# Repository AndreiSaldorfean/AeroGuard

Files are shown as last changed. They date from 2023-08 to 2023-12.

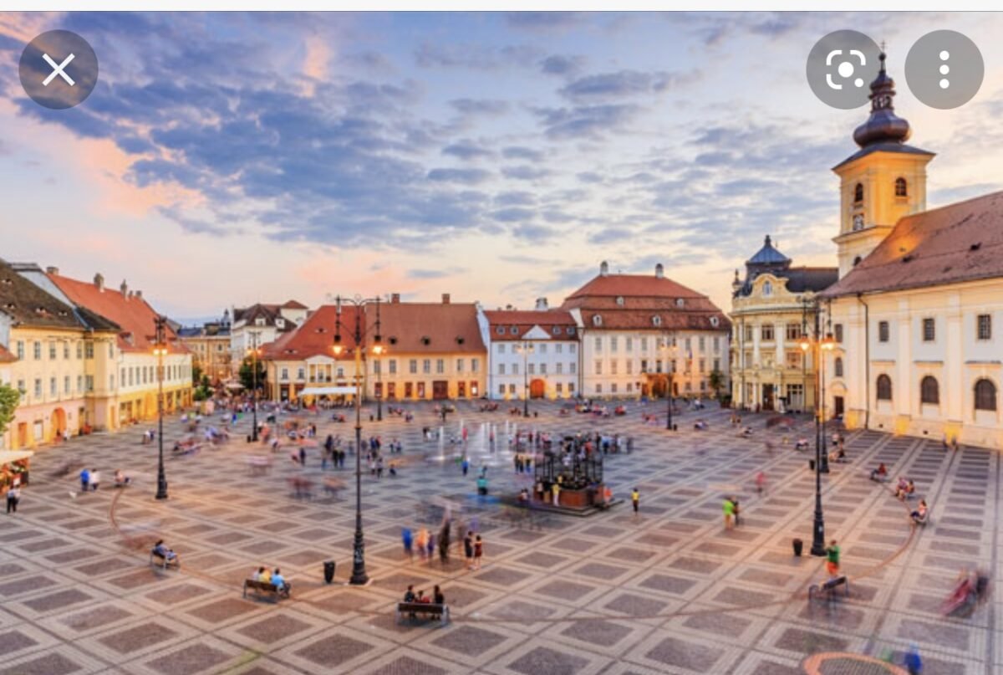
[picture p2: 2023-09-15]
software/poze_website/Centru Sibiu.jpeg

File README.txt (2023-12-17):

Descriere a hartii:

Rosu - Senzori de calitate al aerului.
Mov - Punctul de colectare al datelor.
Verde - Centru de colectare al datelor.

Functionare:

Senzorii ,punctele rosii, sunt alcatuiti din urmatoarele componente:
-LoRa sx1278. Acesta este un  transmitator pe baza de unde radio care are o raza de pana la 5km.
-MQ135, senzor care determina concentratia de C02.
-Arduino nano.
Fiecare senzor, (punctele rosii) masoara concentratia de CO2 a aerului,mai apoi il va trimite catre punctul central care este situat in fiecare cartier.

Punctul central, ( punctele mov ) reprezinta o statie ce va colecta datele de la statiile periferice pentru a le retransmite apoi spre Centru.

Centrul de colectare a datelor, ( punctele verzi ) este un ESP8266 care primeste datele de pe fiecare cartier si le afiseaza pe un site.

Created by: Andrei Saldorfean, Petru Iulian, Neag Mihai, Stancu Tudor

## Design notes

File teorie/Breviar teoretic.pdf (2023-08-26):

# BREVIAR TEORETIC

## 1. Concentrație

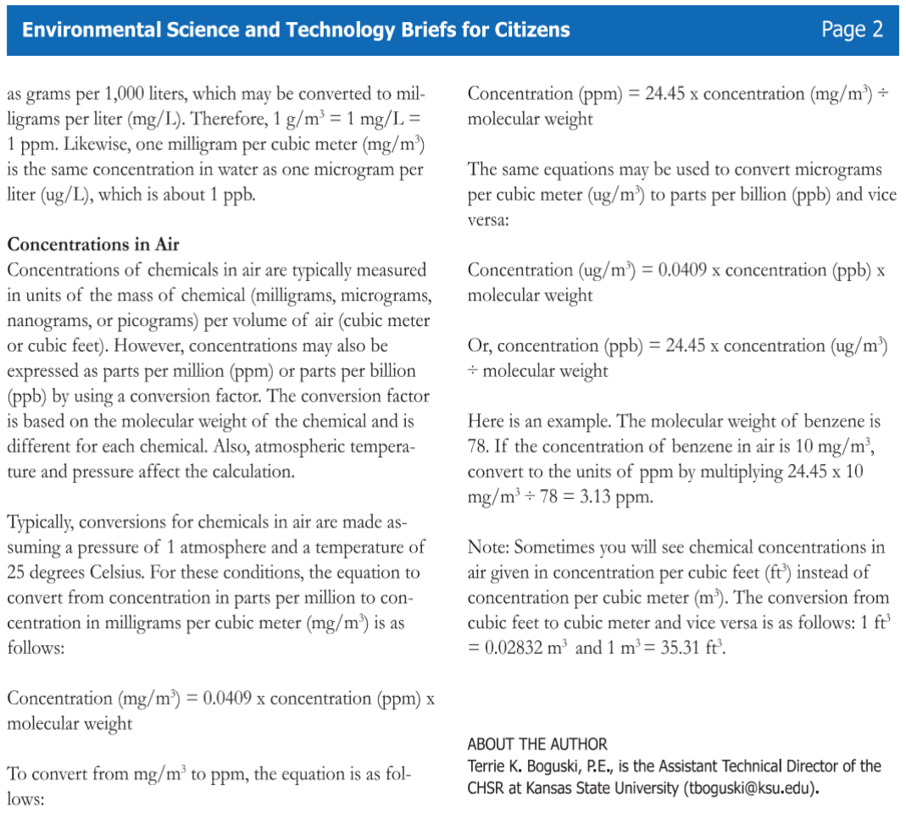
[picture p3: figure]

### 2.Valori

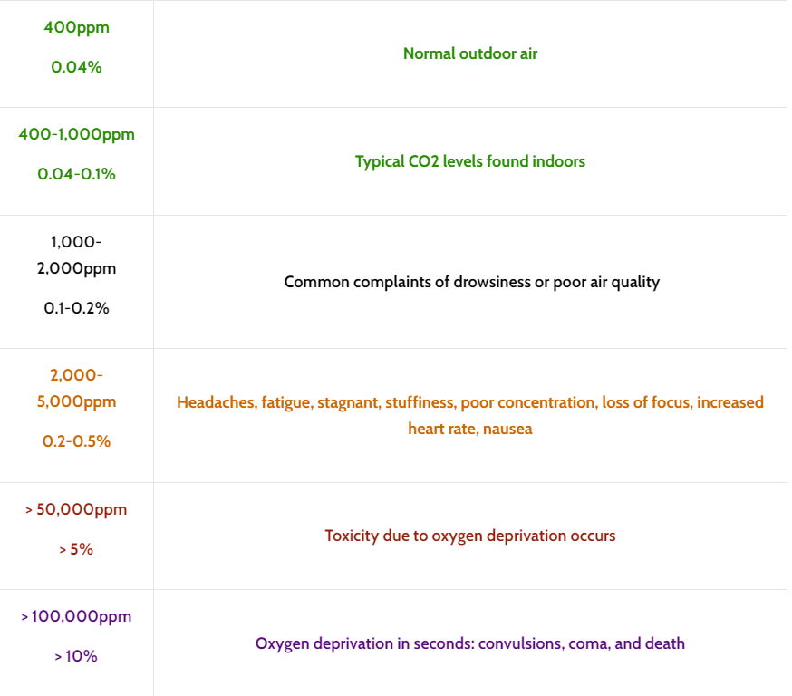
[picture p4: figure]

### 3.Calcul

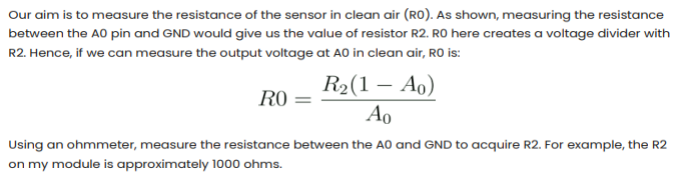
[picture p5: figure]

### Unde: x=concentrație y=Rₛ/R₀ R₂=rezistență potențiometru

### Surse:

https://cfpub.epa.gov/ncer_abstracts/index.cfm/fuseaction/display.files/fileid/14285https://www.co2meter.com/blogs/news/carbon-dioxide-indoor-levels-chart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 ronments%3A%20In%20most,%2C%20offices%2C%20and%20public%20spaces (https://www.co2meter.com/blogs/news/carbon-dioxide-indoor-levels-chart) .https://www.teachmemicro.com/mq-135-air-quality-sensor-tutorial/

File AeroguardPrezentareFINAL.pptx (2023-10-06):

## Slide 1

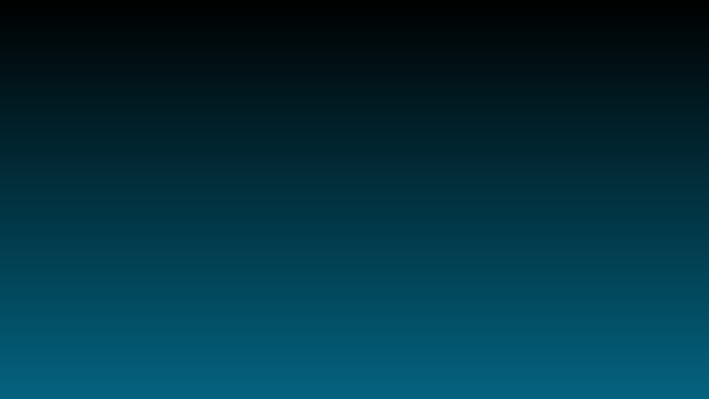
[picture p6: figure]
O imagine care conține albastru, captură de ecran, Albastru electric, estompare Descriere generată automat
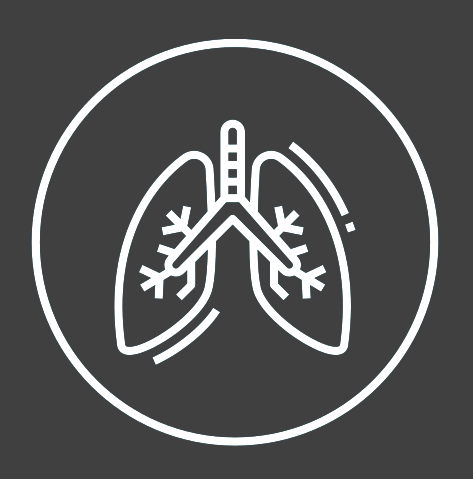
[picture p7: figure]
O imagine care conține simbol, Font, Grafică, siglă Descriere generată automat

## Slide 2

Sistem de măsurare și transmitere a concentrației de dioxid de carbon către un server central.

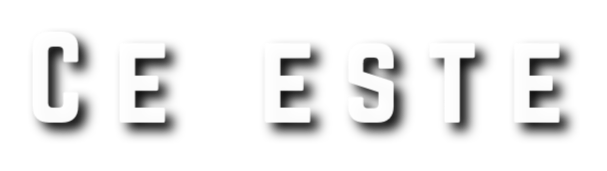
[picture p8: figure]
O imagine care conține Font, Grafică, simbol, siglă Descriere generată automat
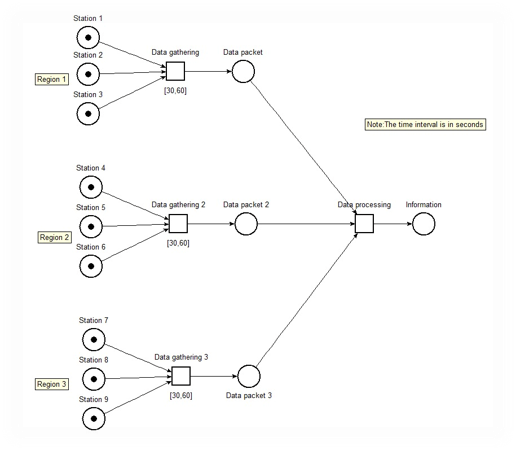
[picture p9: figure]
O imagine care conține text, diagramă, linie, Font Descriere generată automat

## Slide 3

Determinarea cantității de CO2 în raza de acțiune și informarea populației despre gradul de poluare într-o anumită regiune.

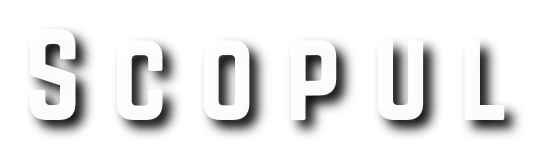
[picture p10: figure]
O imagine care conține Font, Grafică, siglă, simbol Descriere generată automat
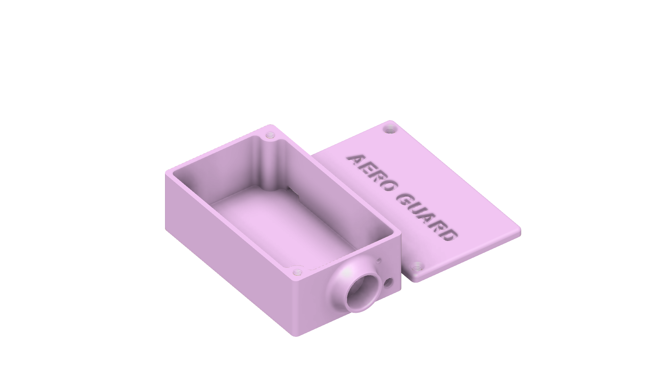
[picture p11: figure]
O imagine care conține cutie, plastic Descriere generată automat

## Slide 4

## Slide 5

Implementare de senzor de temperatura pentru sporirea calitatii masuratorii

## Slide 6

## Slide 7

Ilustrarea grafica a istoricului valorilor

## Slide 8

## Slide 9

Actualizarea informatiilor in timp real

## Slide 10

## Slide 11

Utilizarea unui sistem de avertizare pentru conditii extreme

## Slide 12

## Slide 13

Securizarea dispozitivului prin sistem anti-furt

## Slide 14

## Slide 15

API Key Authorization

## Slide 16

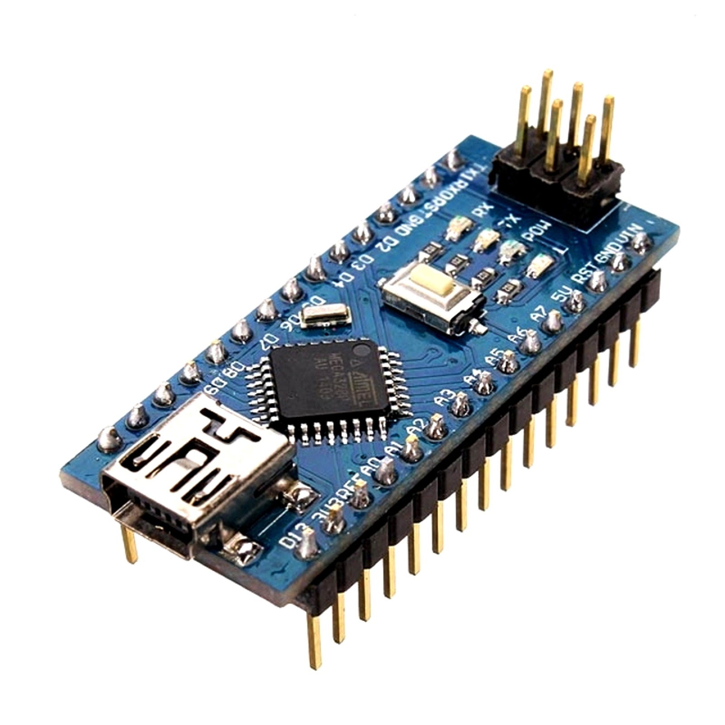
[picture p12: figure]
O imagine care conține Componenta circuitului, Componentă electronică, Componentă de circuit pasiv, Inginerie electronică Descriere generată automat
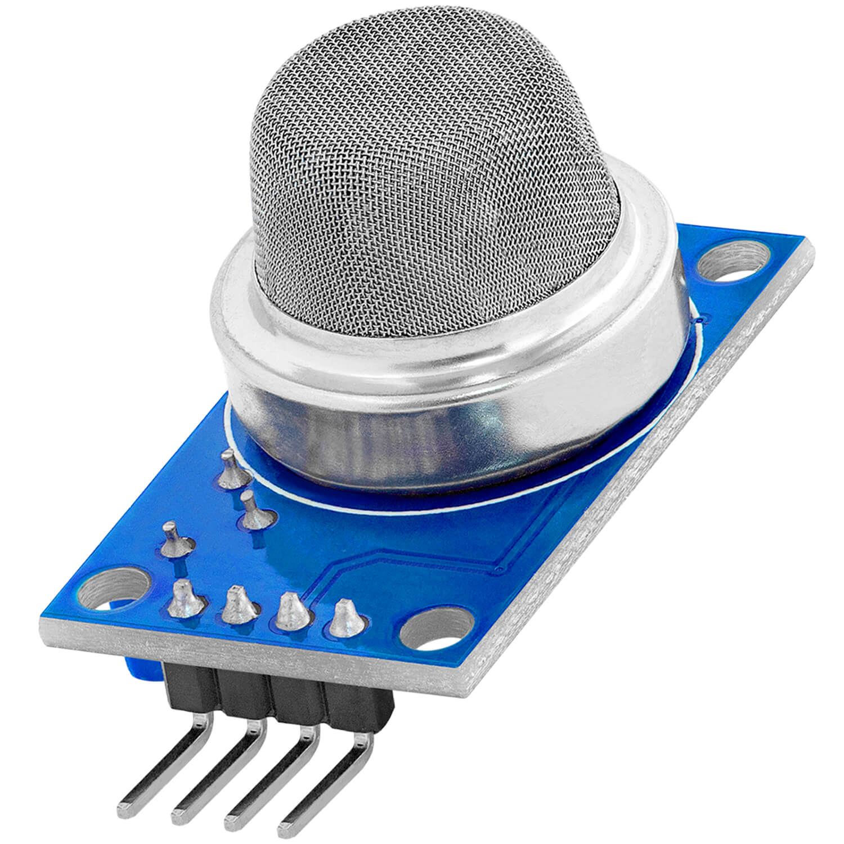
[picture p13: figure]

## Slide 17

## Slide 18

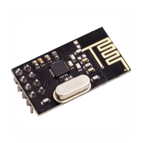
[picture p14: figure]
O imagine care conține electronice, Inginerie electronică, Componenta circuitului, Componentă electronică Descriere generată automat
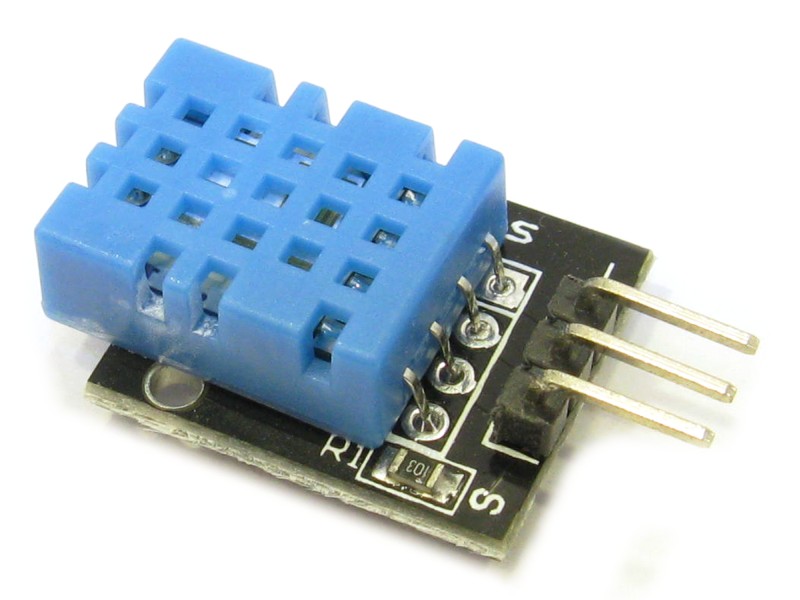
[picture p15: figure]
O imagine care conține Componenta circuitului, Inginerie electronică, Componentă de circuit pasiv, Componentă electronică Descriere generată automat

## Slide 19

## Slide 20

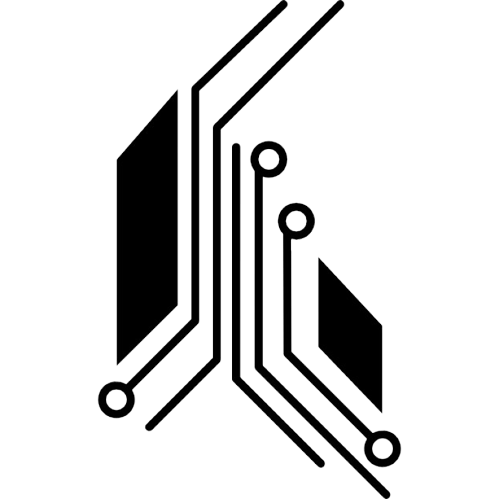
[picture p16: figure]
O imagine care conține captură de ecran, diagramă, proiectare Descriere generată automat
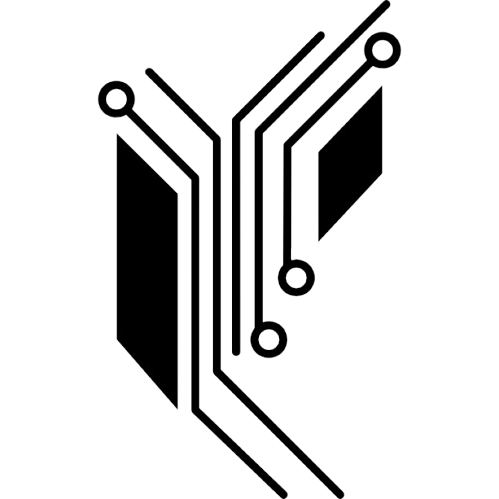
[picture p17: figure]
O imagine care conține captură de ecran, diagramă, proiectare Descriere generată automat
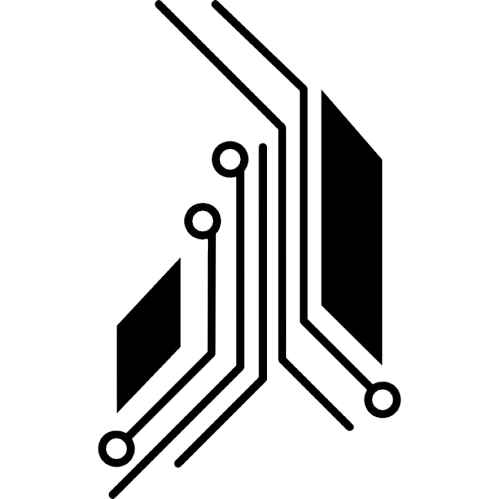
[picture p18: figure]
O imagine care conține captură de ecran, diagramă, proiectare Descriere generată automat
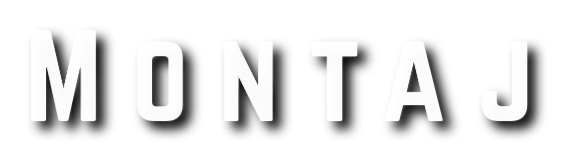
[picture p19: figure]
O imagine care conține Font, Grafică, siglă, tipografie Descriere generată automat
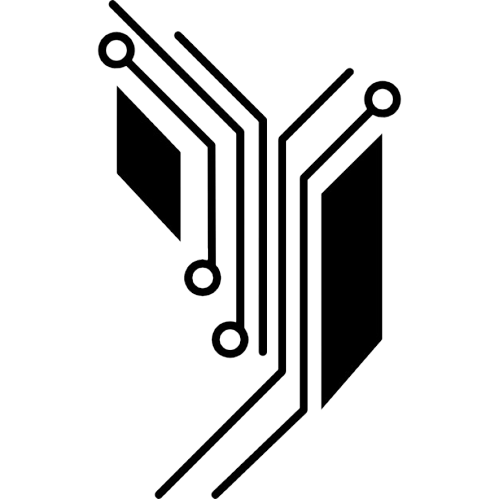
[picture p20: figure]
O imagine care conține captură de ecran, diagramă, proiectare Descriere generată automat
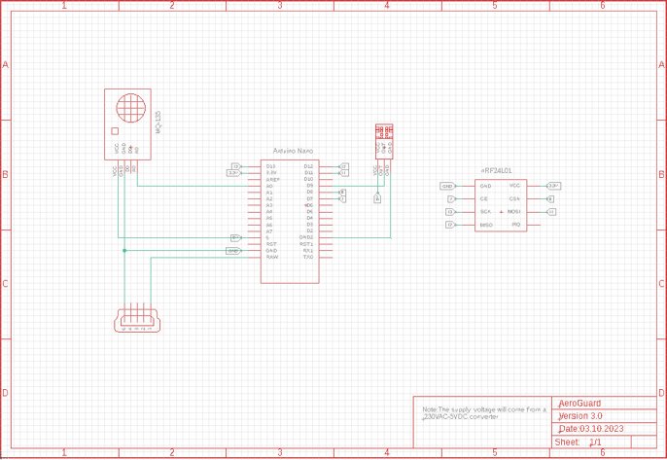
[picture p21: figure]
O imagine care conține text, diagramă, captură de ecran, Paralel Descriere generată automat

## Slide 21

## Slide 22

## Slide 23

EFICIENT - din punct de vedere energetic

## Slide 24

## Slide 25

RENTABIL – componente usor de procurat

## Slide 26

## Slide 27

UZ LONGEVIV – acumulator nu necesita inlocuire

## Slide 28

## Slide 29

ACCESIBIL – usor de utilizat, pentru toata lumea

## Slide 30

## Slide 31

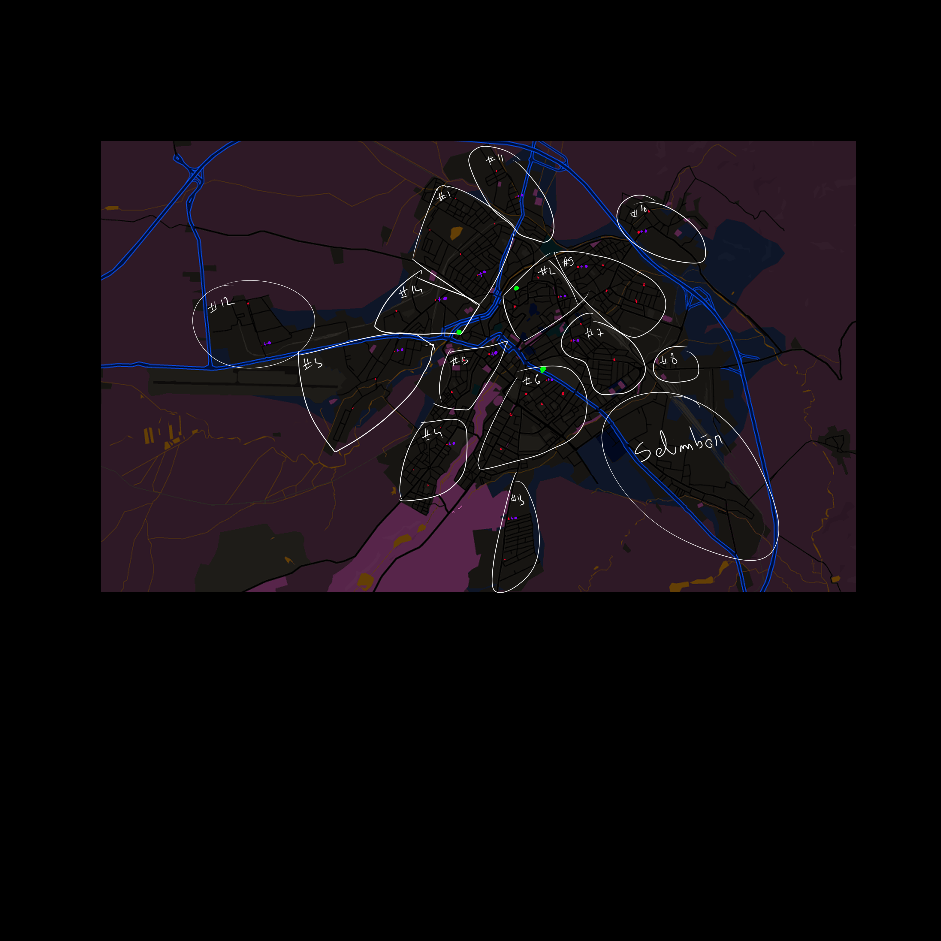
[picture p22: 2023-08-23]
overview.png

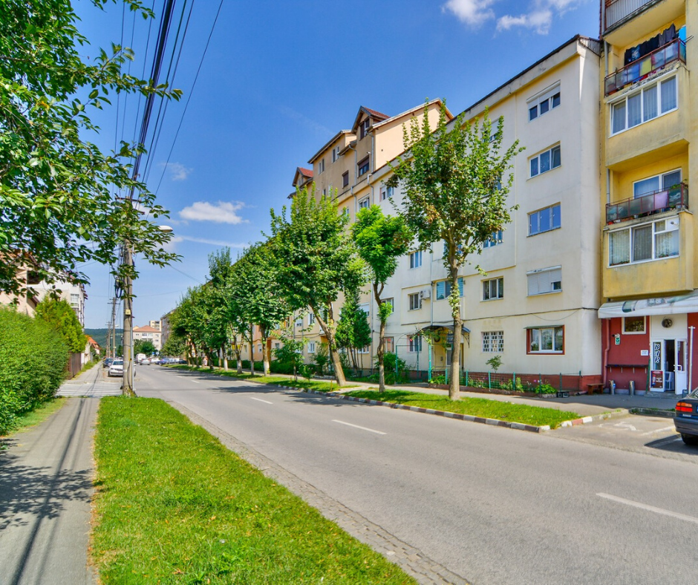
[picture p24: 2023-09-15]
software/poze_website/Vasile Aaron sibiu.png

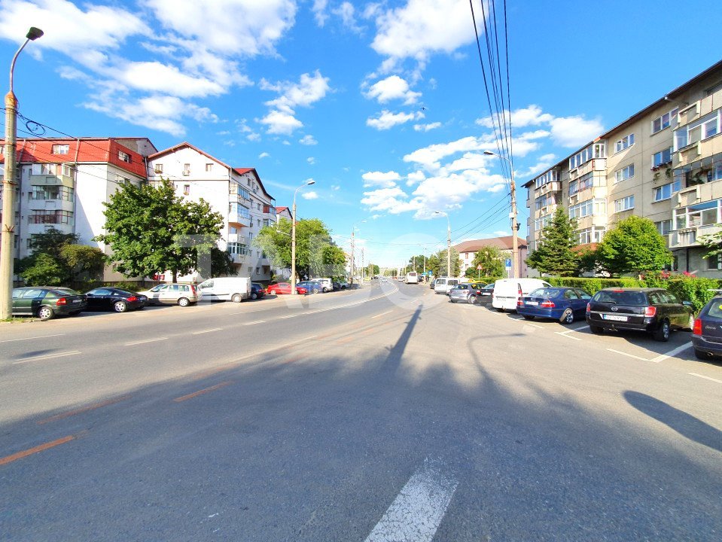
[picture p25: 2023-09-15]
software/poze_website/Broscarie.jpg

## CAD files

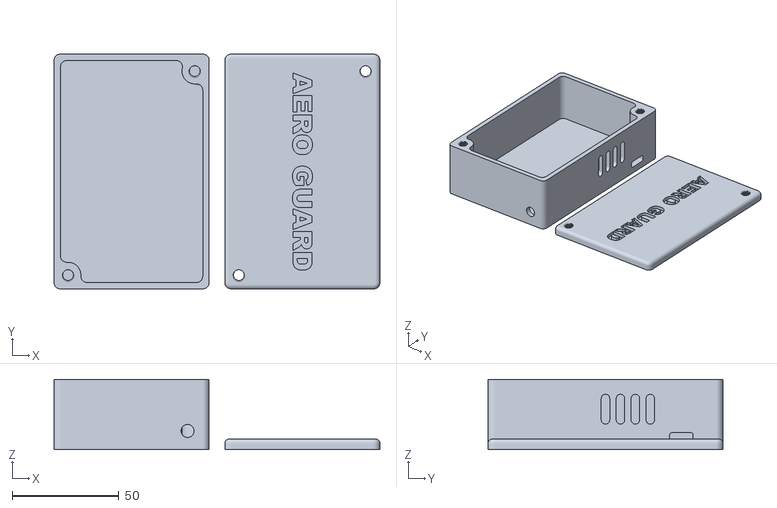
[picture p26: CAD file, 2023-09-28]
hardware/cad/carcase/CaseForESP.stl
152.7 x 110.0 x 33.0

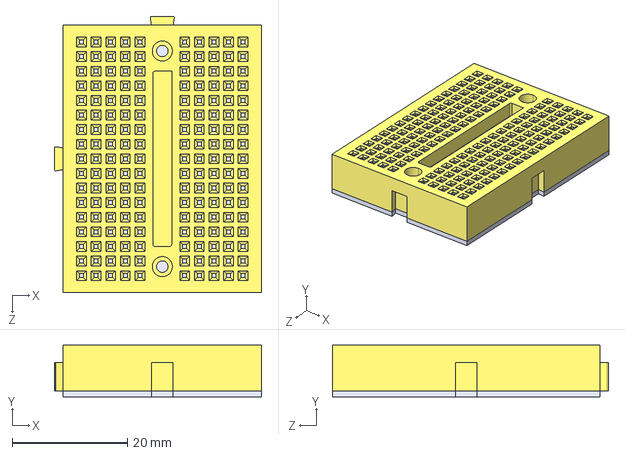
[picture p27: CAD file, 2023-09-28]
hardware/cad/setp/Mini-Breadboard YELLOW.STEP
36.0 x 9.00 x 48.0 mm

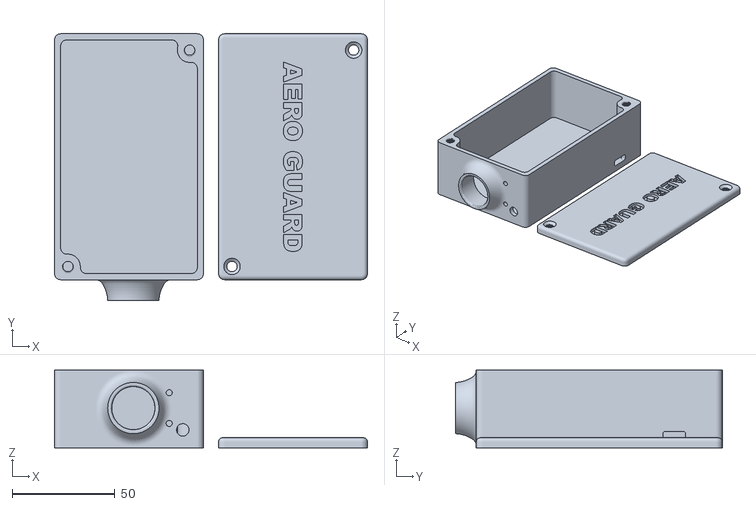
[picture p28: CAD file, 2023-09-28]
hardware/cad/carcase/CaseForNano.stl
152.7 x 130.0 x 38.0

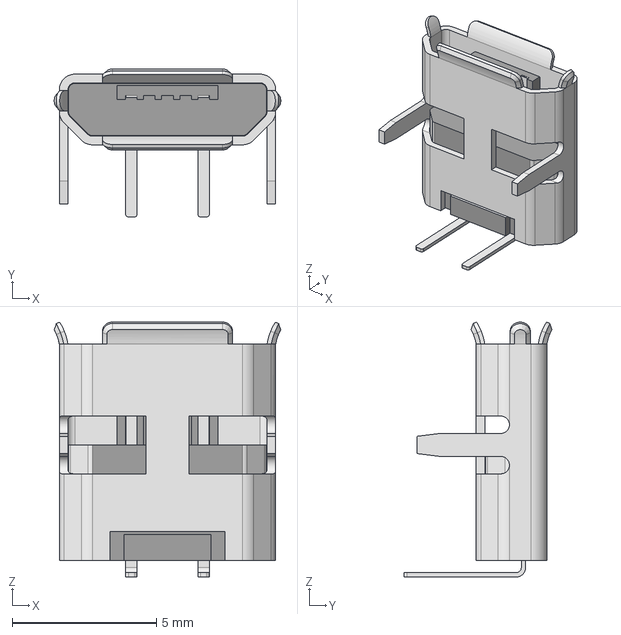
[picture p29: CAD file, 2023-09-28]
hardware/cad/setp/Micro USB 2 pin.stp
7.85 x 5.13 x 8.83 mm

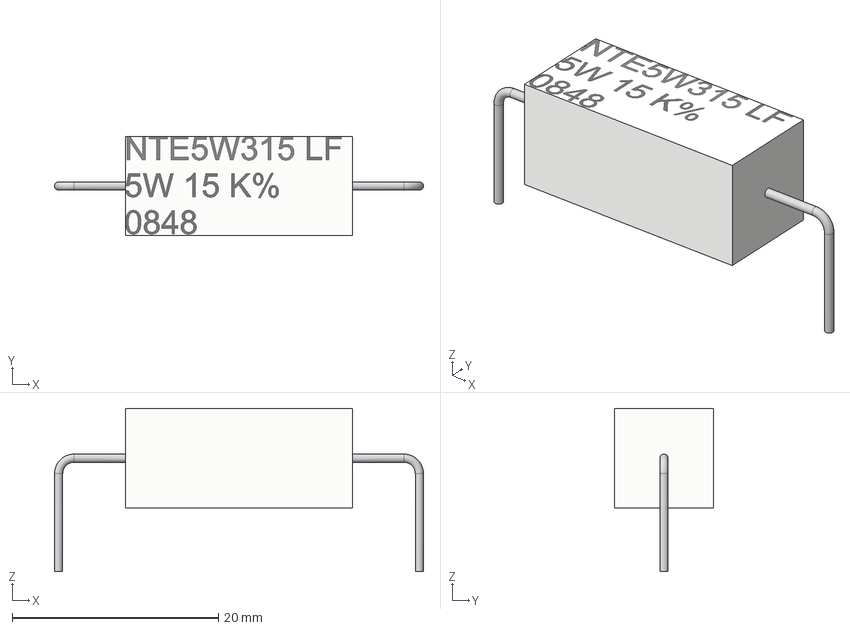
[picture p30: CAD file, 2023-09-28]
hardware/cad/setp/5WD27.step
35.8 x 9.65 x 15.8 mm

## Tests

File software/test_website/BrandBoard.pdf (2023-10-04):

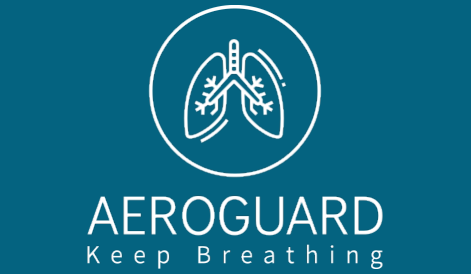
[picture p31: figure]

# Logo Versions

# AEROGUARD

## Primary

Wordmark Only | Icon

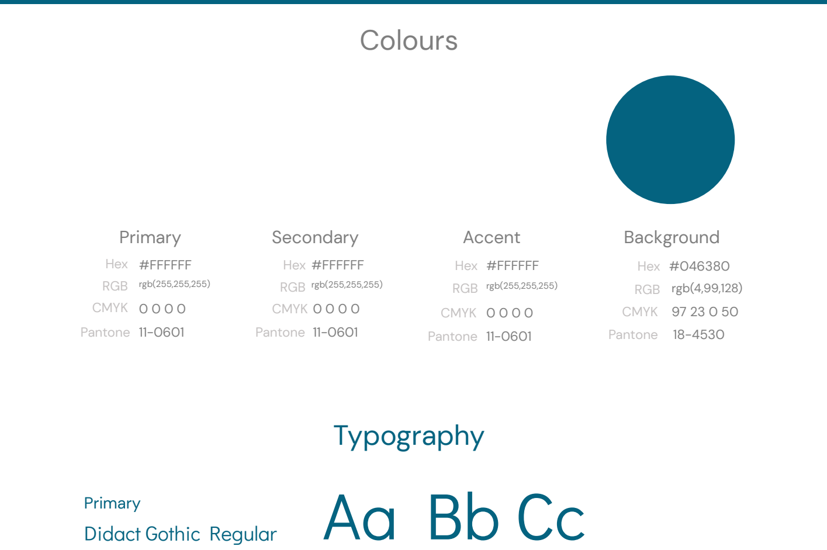
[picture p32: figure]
Made by LOGO.com; Colours; Primary; Secondary; Accent; Background; Hex RGB CMYK; Pantone; #FFFFFF; rgb(255,255,255) 0 0 0 0 11-0601; Hex RGB CMYK Pantone; Hex RGB; CMYK Pantone; rgb(255,255,255); rgb(4,99,128) 97 23 0 50 18-4530; Typography; Primary Didact Gothic Regular

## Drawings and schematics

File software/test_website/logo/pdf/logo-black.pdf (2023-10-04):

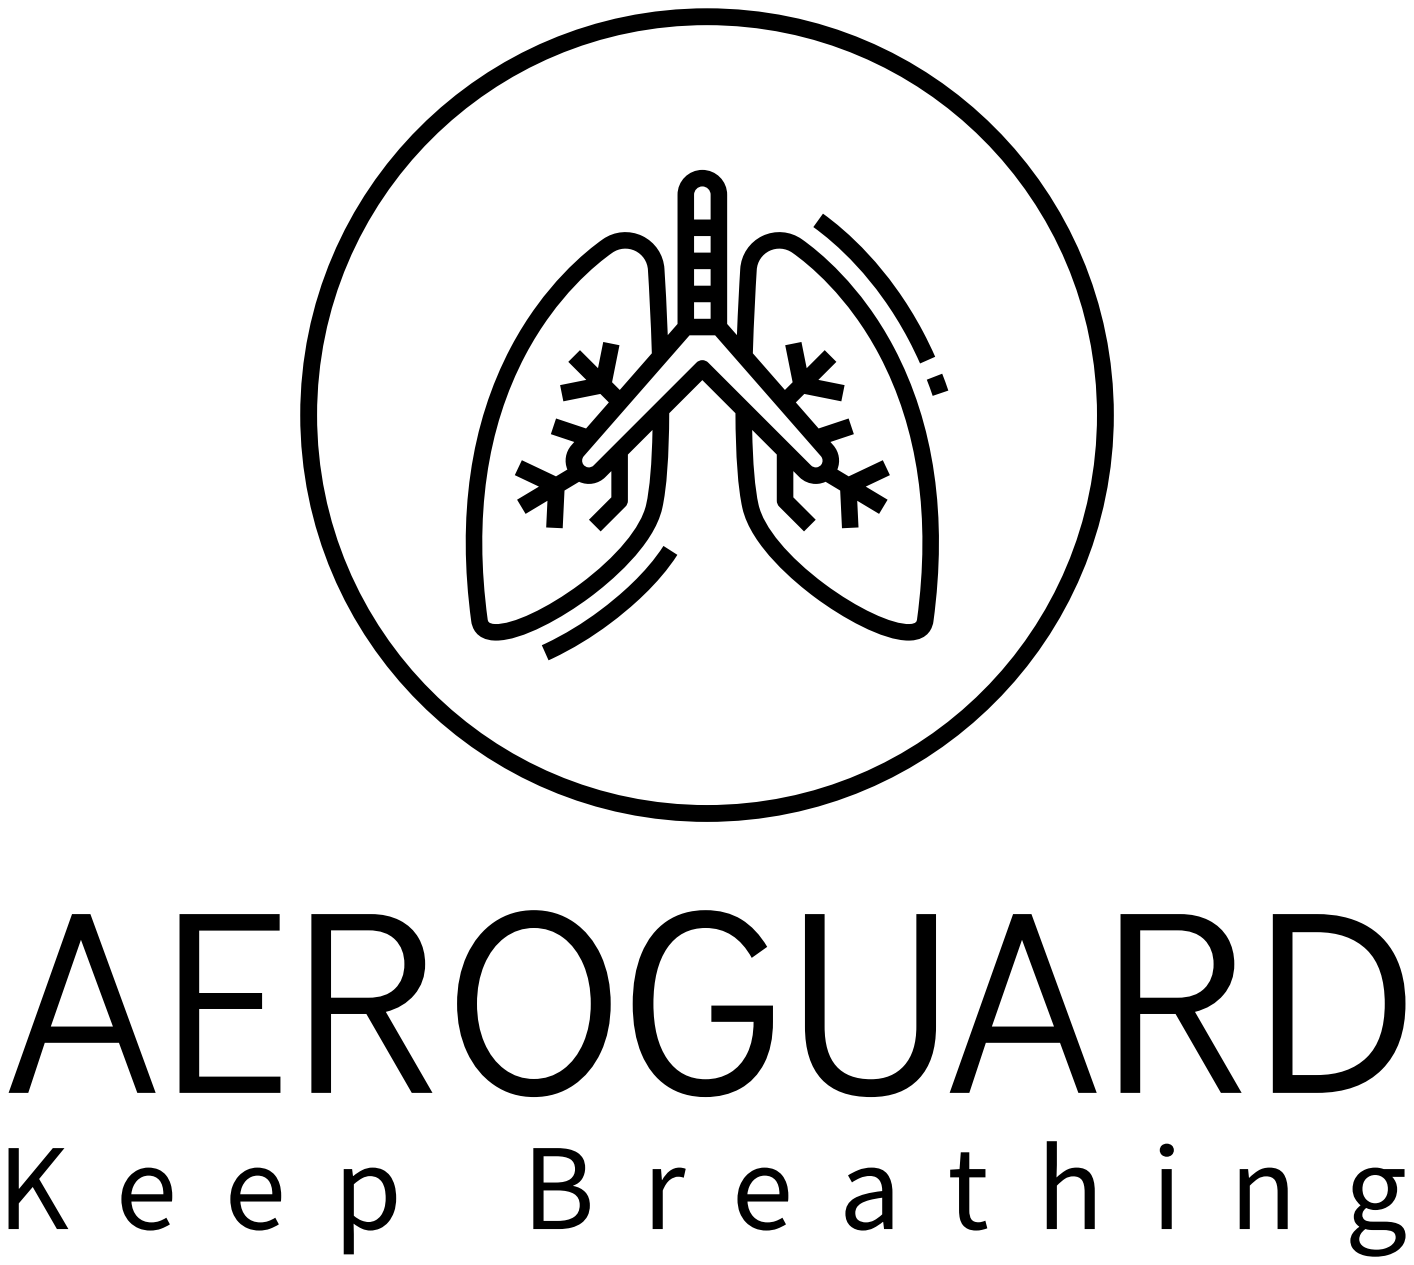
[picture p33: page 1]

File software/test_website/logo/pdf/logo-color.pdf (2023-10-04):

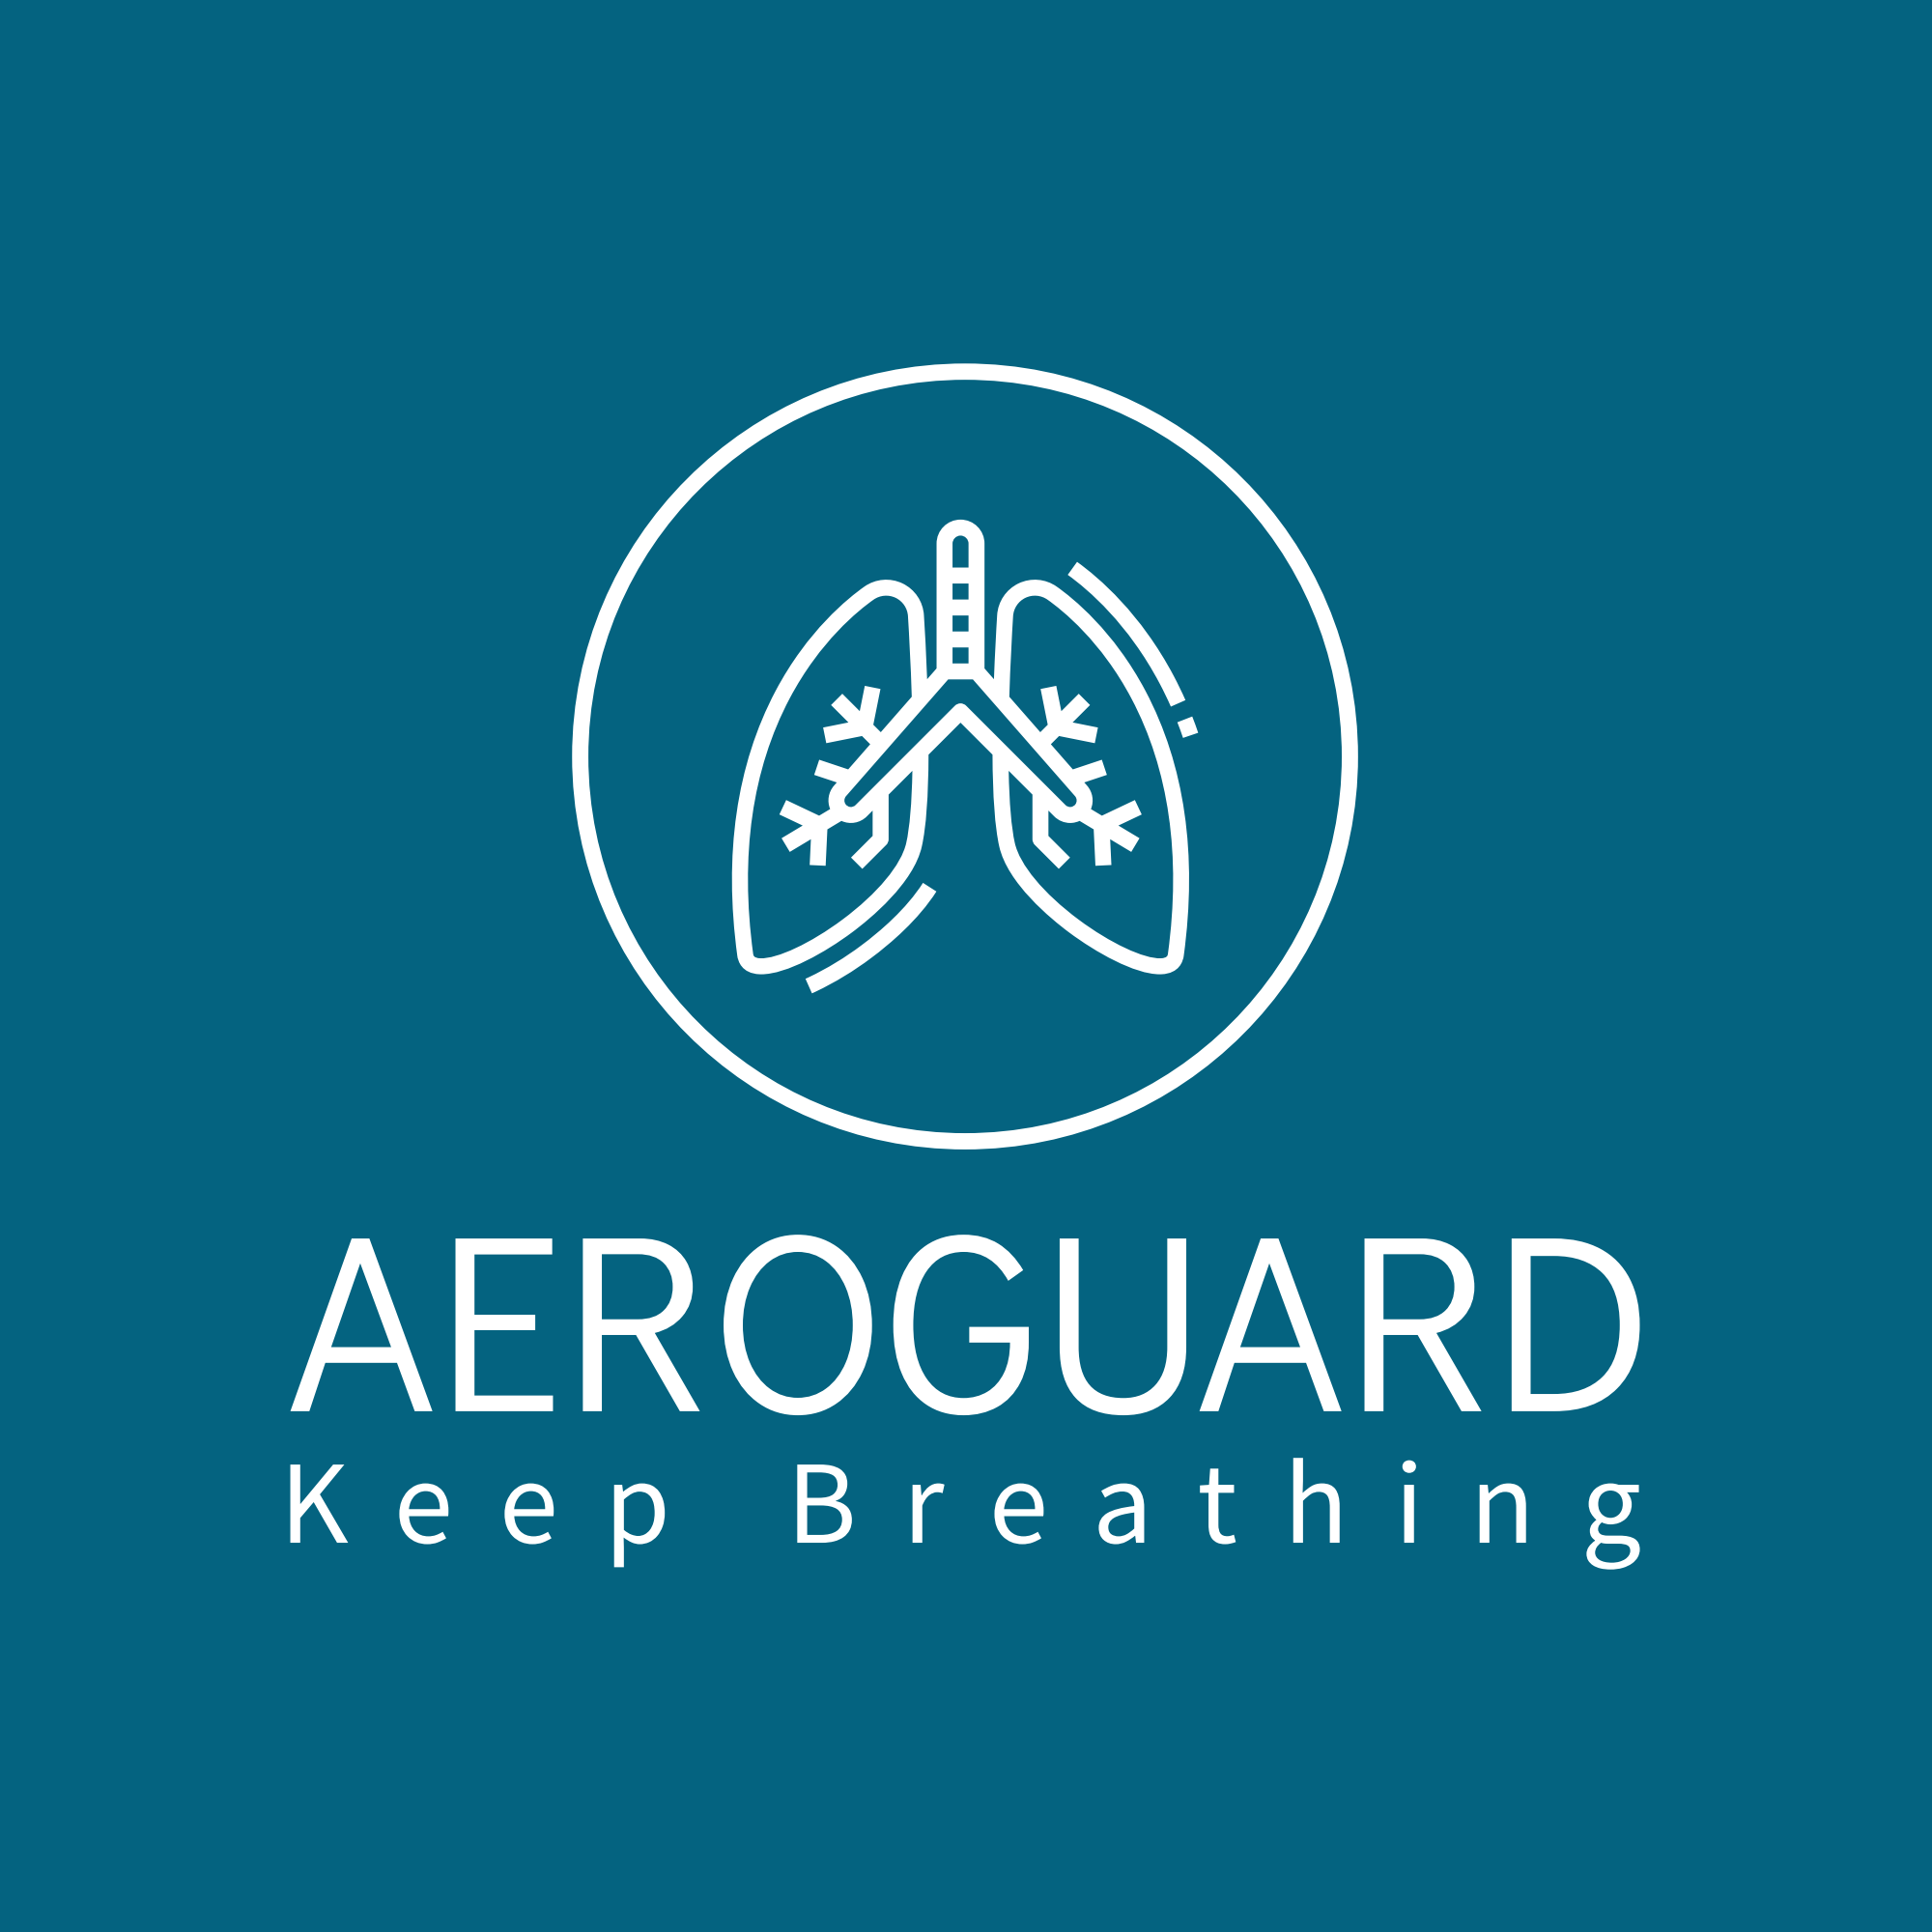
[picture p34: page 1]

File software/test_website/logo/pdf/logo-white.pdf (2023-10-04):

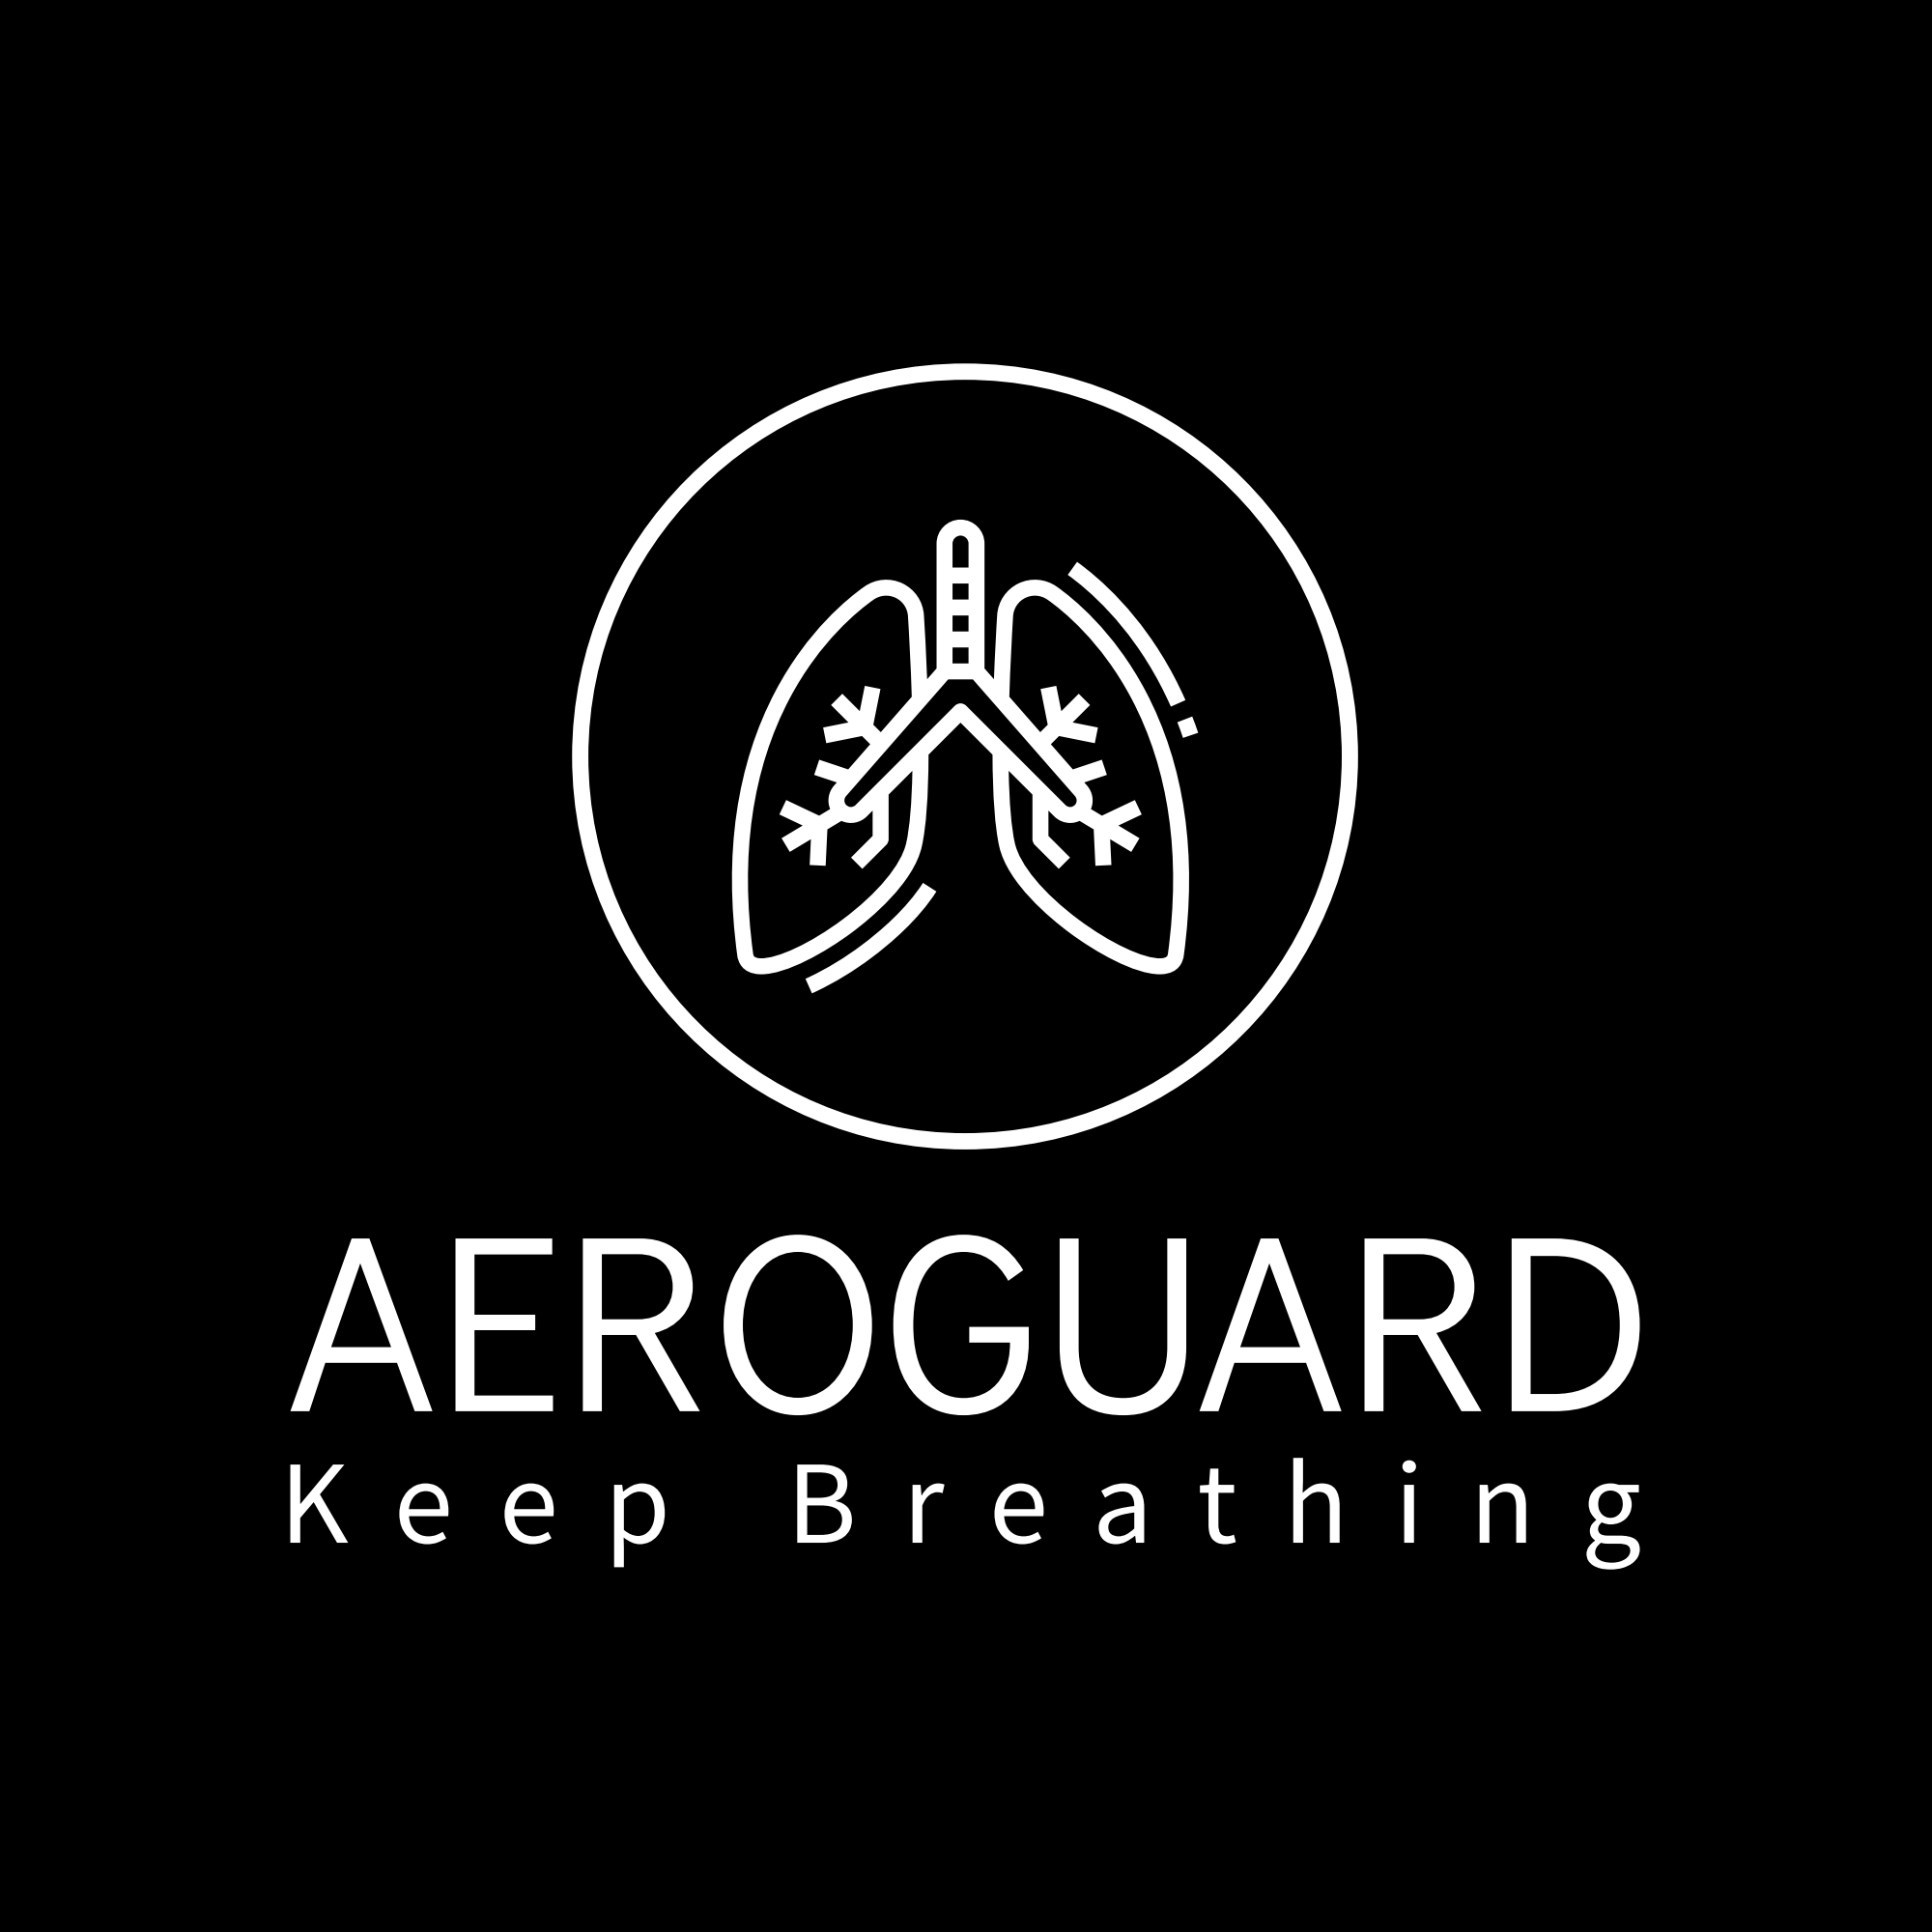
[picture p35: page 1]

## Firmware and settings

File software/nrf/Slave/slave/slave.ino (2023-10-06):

// SimpleTx - the master or the transmitter
#include <SPI.h>
#include <nRF24L01.h>
#include <RF24.h>
#include <MQ135.h>
#include <DHT.h>

#define BUFFER_SIZE 500
#define JSON_SIZE 100  
#define CE_PIN   7
#define CSN_PIN  8
#define DHT_PIN  9
#define MQ135_PIN  A0
#define DHTTYPE DHT11  
#define N 500
int i=0;
float temperature, humidity; // Temp and Humid floats, will be measured by the DHT
float sum=0;
float mean_temp=0;
float mean_hum=0;

const byte address_dev1 = 1;
const byte address_dev2 = 2;
const byte address_dev3 = 3;
const byte address_dev4 = 4; // real values
const byte addresses[4] = {address_dev1,address_dev2,address_dev3,address_dev4};

RF24 radio(CE_PIN, CSN_PIN); // Create a Radio
MQ135 calibration(MQ135_PIN);
DHT dht(DHT_PIN, DHTTYPE);

unsigned long txIntervalMillis = 3000; // send once per second


void setup() {

  Serial.begin(9600);

  if(!radio.begin()){
    Serial.println("Radio Failed");
    while(1){
      delay(200);
    }  
  }
  dht.begin();

  radio.setPALevel(RF24_PA_LOW);
  radio.setDataRate( RF24_250KBPS );
  radio.setRetries(3,5); // delay, count
}

//====================

void loop() {
  sum=0;
  mean_temp=0;
  mean_hum=0;
  initMQ();
  MQ135 sensor(MQ135_PIN,sum/N);
  temperature=mean_temp/N-7;
  humidity=mean_hum/N;
  char buffer[BUFFER_SIZE];
  float ppm=sensor.getCorrectedResistance(temperature,humidity);
  prepare_packet((int)temperature,(int)ppm,buffer);

  radio.openWritingPipe(addresses[0]);
  String str = buffer;
  char start_[32] = "start_of_message";
  radio.write(&start_,sizeof(start_));
  Serial.println(start_);
  int n = str.length(),ct=0,j=1,si=0;
  while(str.length()!=0){
      if(ct==32){
          String message = str.substring(0,32);
          char temp[33];
          message.toCharArray(temp,33);
          Serial.println(temp);
          radio.write(&temp,sizeof(temp)+1);
          ct=0;  
          str.remove(0,32);
          delay(1000);
      }
      if(str.length()<32){
          String message = str.substring(0,str.length());
          char temp[32];
          message.toCharArray(temp,32);
          Serial.println(temp);
          radio.write(&temp,sizeof(temp)+1);
          str.remove(0,str.length());
          delay(1000);
      }
      ct++;
    }
  char end_[32] = "end_of_message";
  radio.write(&end_,sizeof(end_));
  Serial.println(end_);
  // radio.write(&buffer,sizeof(buffer));
  // Serial.println(buffer);
  delay(txIntervalMillis);
}
void halt(int n){
  while(1){
    delay(n);
  }
}
//====================

void prepare_packet(int temperatura,int concentratie,char buffer[BUFFER_SIZE]){
    start_move(buffer,"[");  
    char json[200] ="";
    prepare_json(json,"2,", "\"Strada_Orhideelor\",", "2,","18");
    move(buffer,json);
    move(buffer,",");

    json[200] ="";
    prepare_json(json,"3,", "\"Strada_Eschil\",", "5,","19");
    move(buffer,json);
    move(buffer,",");
    

    json[200] ="";
    prepare_json(json,"1,", "\"Strada_Lunga\",", "3,","17");
    move(buffer,json);
    move(buffer,",");

    json[200] ="";
    prepare_json(json,"5,", "\"Strada_Tiglari\",", "4,","20");
    move(buffer,json);
    move(buffer,",");

    //VALORI REALE
    json[200] ="";
    prepare_final_json(json,"0,", "\"Incapere\",", concentratie,temperatura,"\"Terezian\"");
    move(buffer,json);
    move(buffer,"]");
}
//====================

void send(int n,char message[BUFFER_SIZE]) {
  radio.write(&message,sizeof(message));
  Serial.println(message);
}


// void send_all(){
//   send(addresses[0],1);
//   delay(200);
//   send(addresses[1],2);
//   delay(200);
//   send(addresses[2],3);
// }

int size_(char input[5]){
    int i=0;
    while(input[i] != '\0'){
      i++;
    }
    return i;
}

void to_char(int val,char out[5]){
    String temp;
    temp = String(val);
    for(int i=0;i<sizeof(temp);i++){
      out[i] = temp[i];
    }
    out[sizeof(temp)] ='\0';
}

void to_int(int& out,char input[5]){
    out = 0;
    int s = size_(input);
    for(int i=0;i<s;i++){
        out =out*10;
        out = out +(input[i]-'0');
    }
}

void move(char out[32], const char var[32]){
  int j=0;
  for(int i=size_(out);i<=size_(var) + size_(out);i++){
    out[i] = var[j++];
  }
}

void start_move(char out[32], const char var[32]){
  int j=0;
  for(int i=0;i<=size_(var);i++){
    out[i] = var[j++];
  }
}

void prepare_json(char json[JSON_SIZE],char id[5],char strada[32],char concentratie[5],char temperatura[5]){
  start_move(json,"{\"Id\":");
  move(json,id);
  move(json,"\"Strada\":");
  move(json,strada);
  move(json,"\"Concentratie\":");
  move(json,concentratie);
  move(json,"\"Temperatura\":");
  move(json,temperatura);
  move(json,"}");
}

void prepare_final_json(char json[JSON_SIZE],char id[5],char strada[32],int concentratie,int temperatura,char zona[20]){

  start_move(json,"{\"Id\":");
  move(json,id);
  move(json,"\"Strada\":");
  move(json,strada);
  move(json,"\"Concentratie\":");
  
  //Transformam concentratia in ex: "20,"
  char concentratie_[5];
  to_char(concentratie, concentratie_);
  //====================================
  move(json,concentratie_);
  move(json,",");

  move(json,"\"Temperatura\":");
  //Transformam temperatura in ex: "18,"
  char temperatura_[5];
  to_char(temperatura, temperatura_);
  //====================================
  move(json,temperatura_);
  move(json,",");

  move(json,"\"Zona\":");
  move(json,zona);
  move(json,"}");
}

void initMQ(){
  humidity = dht.readHumidity();
  temperature = dht.readTemperature();
  for(int i=0;i<N/2;i++)
  {
    mean_temp=dht.readTemperature()+mean_temp;
    mean_hum=dht.readHumidity()+mean_hum;
    
  }
  for(int i=0;i<N;i++)
    sum=sum+calibration.getCorrectedResistance(mean_temp/N, mean_hum/N);
  delay(200);
}

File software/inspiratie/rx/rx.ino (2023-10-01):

// An example demonstrating the multiceiver capability of the NRF24L01+
// in a star network with one PRX hub and up to six PTX nodes

//This sketch is a modification from a video on the ForceTronics YouTube Channel,
//which code was leveraged from http://maniacbug.github.io/RF24/starping_8pde-example.html
//This sketch is free to the public to use and modify at your own risk

#include <SPI.h> //Call SPI library so you can communicate with the nRF24L01+
#include <nRF24L01.h> //nRF2401 libarary found at https://github.com/tmrh20/RF24/
#include <RF24.h> //nRF2401 libarary found at https://github.com/tmrh20/RF24/

const int pinCE = 4; //This pin is used to set the nRF24 to standby (0) or active mode (1)
const int pinCSN = SS; //This pin is used to tell the nRF24 whether the SPI communication is a command or message to send out
RF24 radio(pinCE, pinCSN); // Declare object from nRF24 library (Create your wireless SPI)

//Create up to 6 pipe addresses P0 - P5;  the "LL" is for LongLong type
const uint64_t rAddress[] = {0x7878787878LL, 0xB3B4B5B6F1LL, 0xB3B4B5B6CDLL, 0xB3B4B5B6A3LL, 0xB3B4B5B60FLL, 0xB3B4B5B605LL };

byte daNumber = 0; //The number that the transmitters are trying to guess

void setup()   
{
  randomSeed(analogRead(0)); //create unique seed value for random number generation
  daNumber = (byte)random(11); //Create random number that transmitters have to guess
  Serial.begin(9600);  //start serial to communication
  Serial.print("The number they are trying to guess is: "); 
  Serial.println(daNumber); //print the number that they have to guess
  Serial.println();
  radio.begin();  //Start the nRF24 module

  radio.setPALevel(RF24_PA_LOW);  // "short range setting" - increase if you want more range AND have a good power supply
  radio.setChannel(108);          // the higher channels tend to be more "open"

  // Open up to six pipes for PRX to receive data
  radio.openReadingPipe(0,rAddress[0]);
  radio.openReadingPipe(1,rAddress[1]);
  radio.openReadingPipe(2,rAddress[2]);
  radio.openReadingPipe(3,rAddress[3]);
  radio.openReadingPipe(4,rAddress[4]);
  radio.openReadingPipe(5,rAddress[5]);
  
  radio.startListening();                 // Start listening for messages
}

void loop()  
{   
    byte pipeNum = 0; //variable to hold which reading pipe sent data
    byte gotByte = 0; //used to store payload from transmit module
    
    while(radio.available(&pipeNum)){ //Check if received data
     radio.read( &gotByte, 1 ); //read one byte of data and store it in gotByte variable
     Serial.print("Received guess from transmitter: "); 
     Serial.println(pipeNum + 1); //print which pipe or transmitter this is from
     Serial.print("They guess number: ");
     Serial.println(gotByte); //print payload or the number the transmitter guessed
     if(gotByte != daNumber) { //if true they guessed wrong
      Serial.println("Fail!! Try again."); 
     }
     else { //if this is true they guessed right
      if(sendCorrectNumber(pipeNum)) Serial.println("Correct! You're done."); //if true we successfully responded
      else Serial.println("Write failed"); //if true we failed responding
     }
     Serial.println();
    }

   delay(200);    
}

 //This function turns the receiver into a transmitter briefly to tell one of the nRF24s
//in the network that it guessed the right number. Returns true if write to module was
//successful
bool sendCorrectNumber(byte xMitter) {
    bool worked; //variable to track if write was successful
    radio.stopListening(); //Stop listening, start receiving data.
    radio.openWritingPipe(rAddress[xMitter]); //Open writing pipe to the nRF24 that guessed the right number
      // note that this is the same pipe address that was just used for receiving
    if(!radio.write(&daNumber, 1))  worked = false; //write the correct number to the nRF24 module, and check that it was received
    else worked = true; //it was received
    radio.startListening(); //Switch back to a receiver
    return worked;  //return whether write was successful
}

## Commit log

2023-08-23 –allow-empty-message
2023-08-24 Harta networkului de senzori montati in sibiu
2023-08-25 Update README.txt
    Am facut si eu un update la readme ca sa avem si noi o prezentare la ce facem
2023-09-01 Add files via upload
    Completare schema electrica
    [montaj_electric.sch]
2023-09-12 modul regulator tensiune 5V-3.3V
2023-09-15 Am adaugat codu pentru lora (Nu e nici pe aproape gata, l-am salvat numa asa ca sa pot lucra la el cand am chef)
    [AeroGuardCase2 v13.stl]
2023-09-26 Adaugare montaj nou
    [montaj_electric_nou.sch]
2023-09-28 Huge update
    [5WD27.step, CaseForESP v3.stl, CaseForNano v5.stl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]
2023-10-01 de cercetat
2023-10-03 Adaugare modul DHT11
    [montaj_lora.sch, montaj_nrf24l01.sch]
